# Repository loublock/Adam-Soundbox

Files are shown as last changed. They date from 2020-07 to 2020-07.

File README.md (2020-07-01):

# Soundbox

Dieses Projekt beinhaltet die Arduino Firmware, die iOS-App, die Ordnerstruktur für das Soundmodul, die CAD-Zeichnungen und die .stl-Files für die druckbaren Teile der Soundbox. 

Die Soundbox funktioniert wie folgt: Beim Einschalten wird das Soundfile 001.mp3 (variabel) aus dem Verzeichnis 01 abgespielt.
Anschließend wird ein silence-Audiofile [1] (Verzeichnis 02) in der Dauerschleife abgespielt. 
Das ist notwendig, da die Drücker mit den Audiofiles aus dem ADVERT Verzeichnis verlinkt sind und diese nur 
ausgeführt werden können, wenn bereits eine Audiodatei abgespielt wird.

Jedem Drücker kann nun Audiofile aus dem Verzeichnis ADVERT zugeordnet werden, mit der MODE (M) Taste kann
zwischen den drei Belegungslayern durchgeschaltet werden. Beim Drücken der RADIO (R) Taste werden die 
Audiofiles im MP3-Verzeichnis geshuffelt. Bei wiederholtem drücken wird ein neuer Song gestartet. 
Die Dateien im MP3-Verzeichnis müssen durchnummeriert werden (0001-9999), beachte die führenden Nullen,
es ergibt sich immer eine Zahl aus vier Ziffern. Das beigelegte rename.py file kann eure Songs automatisch umbenennen.

Die iOS-App ist eine Soundbox To-Go. Sie umfasst die selben Funktionen wie die Hardwarebox und ist in der Lage
sich mit der Soundbox via BLE zu koppeln. In diesem Modus dient die App als Remote Control für die Soundbox.

Wenn ihr eure eigene Soundbox bauen möchtet, müsst ihr folgende Schritte durchführen:

1. Klont euch das Projekt, oder downloaded es als .zip File.
2. Ladet euch die adambox.ino auf euren Arduino Nano (es müssen noch die entsprechenden Libs installiert werden).
3. Druckt euch die .stl-Files aus.
4. Verdrahtet die Hardware nach Schaltplan.
5. Baut die Box nach der CAD-Zeichnung zusammen.
6. Kopiert eure Soundfiles in die entsprechenden Verzeichnisse (siehe SD-Card). Alternativ können auch die Adamfiles genutzt werden.
7. Optional: Kopiert das Xcode Projekt, compiliert es und wählt als Target euer angeschlossenes iOS-Device aus.

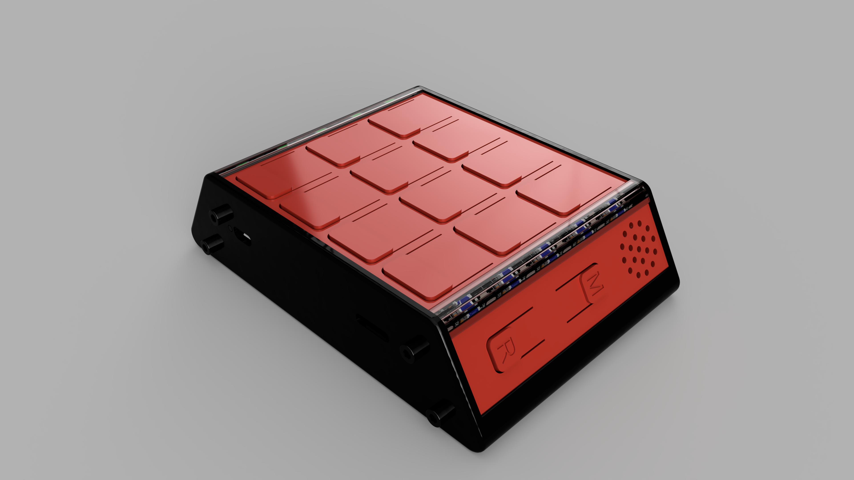
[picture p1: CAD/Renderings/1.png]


App als Soundbox           |  App als remote control
:-------------------------:|:-------------------------:
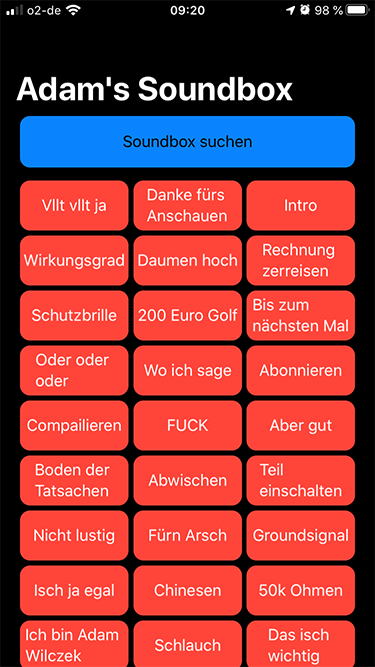
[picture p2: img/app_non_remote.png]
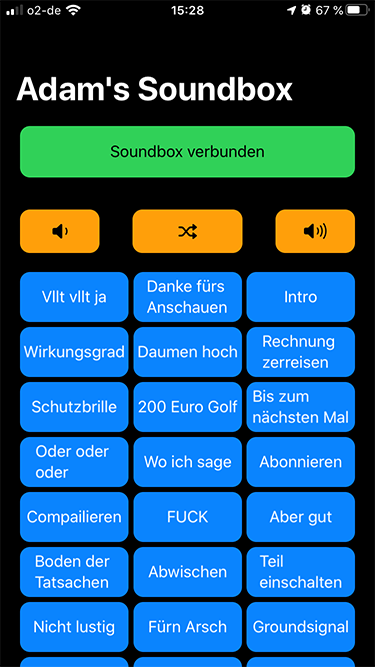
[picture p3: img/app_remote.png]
|  

1 Anar Software LLC, https://github.com/anars/blank-audio

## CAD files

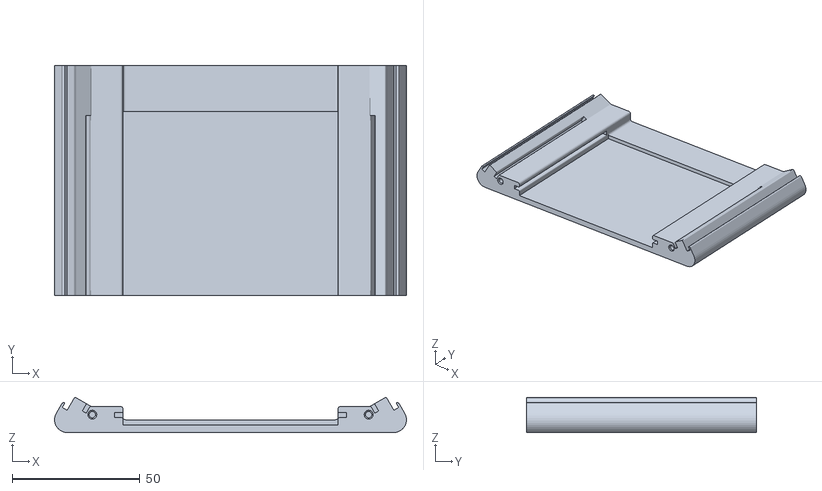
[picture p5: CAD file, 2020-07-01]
CAD/STLs/MainHousingBack.stl
137.8 x 90.0 x 13.7

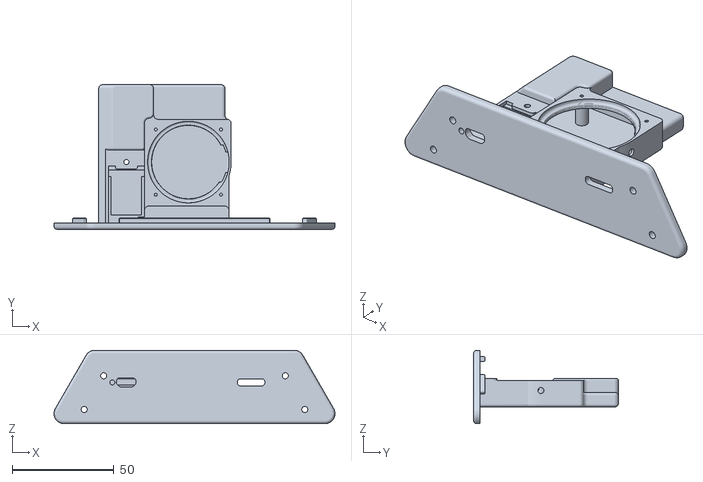
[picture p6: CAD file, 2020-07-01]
CAD/STLs/LowerSpeakerHousing.stl
137.9 x 71.0 x 36.1

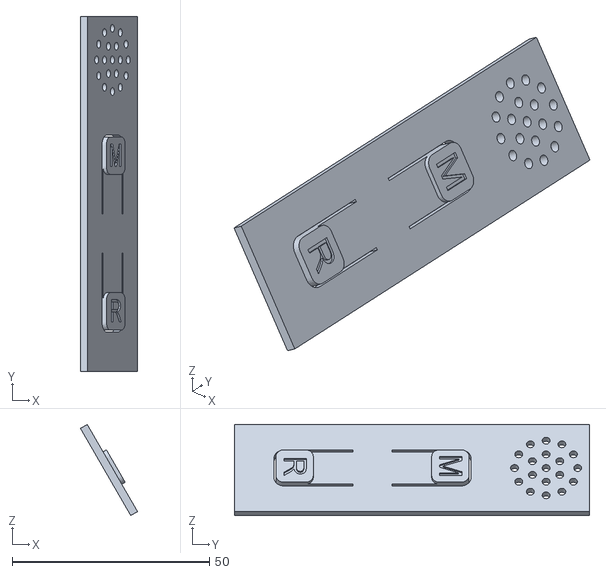
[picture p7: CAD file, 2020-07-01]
CAD/STLs/ButtonplateRight.stl
14.5 x 90.0 x 23.1

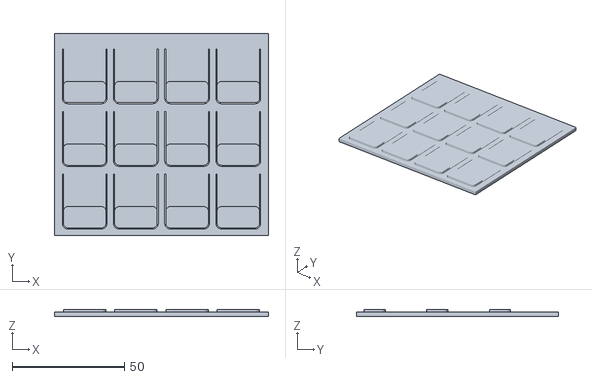
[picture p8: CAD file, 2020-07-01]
CAD/STLs/ButtonPlateTop.stl
95.5 x 90.0 x 3.00

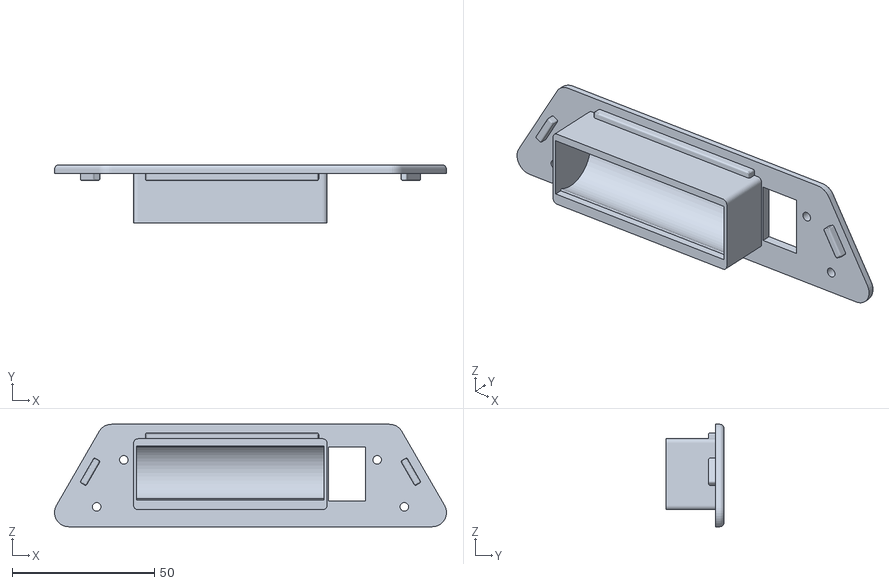
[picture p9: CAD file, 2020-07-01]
CAD/STLs/UpperBatteryHousing.stl
137.8 x 20.5 x 36.1

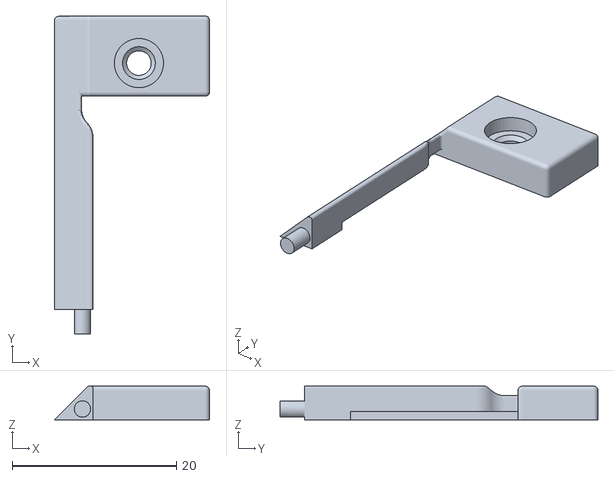
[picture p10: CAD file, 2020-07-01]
CAD/STLs/ChargingLightClamp.stl
18.9 x 38.8 x 4.10

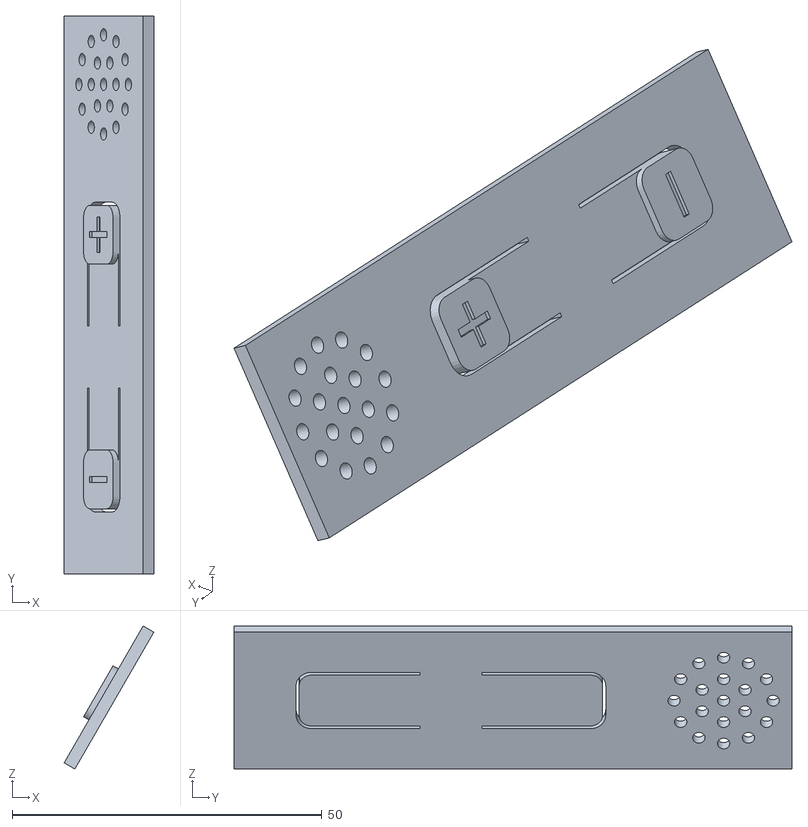
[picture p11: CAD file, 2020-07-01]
CAD/STLs/ButtonplateLeft.stl
14.5 x 90.0 x 23.1

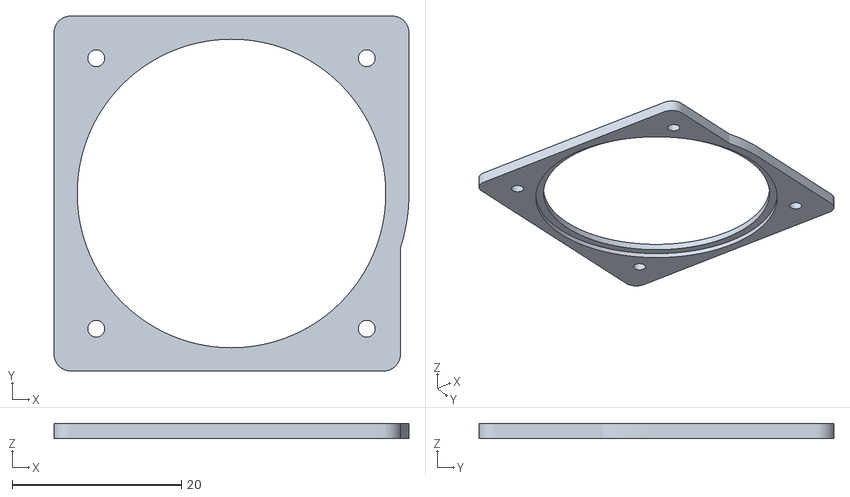
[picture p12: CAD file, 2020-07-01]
CAD/STLs/SpeakerhousingClamp.stl
42.0 x 42.0 x 1.75

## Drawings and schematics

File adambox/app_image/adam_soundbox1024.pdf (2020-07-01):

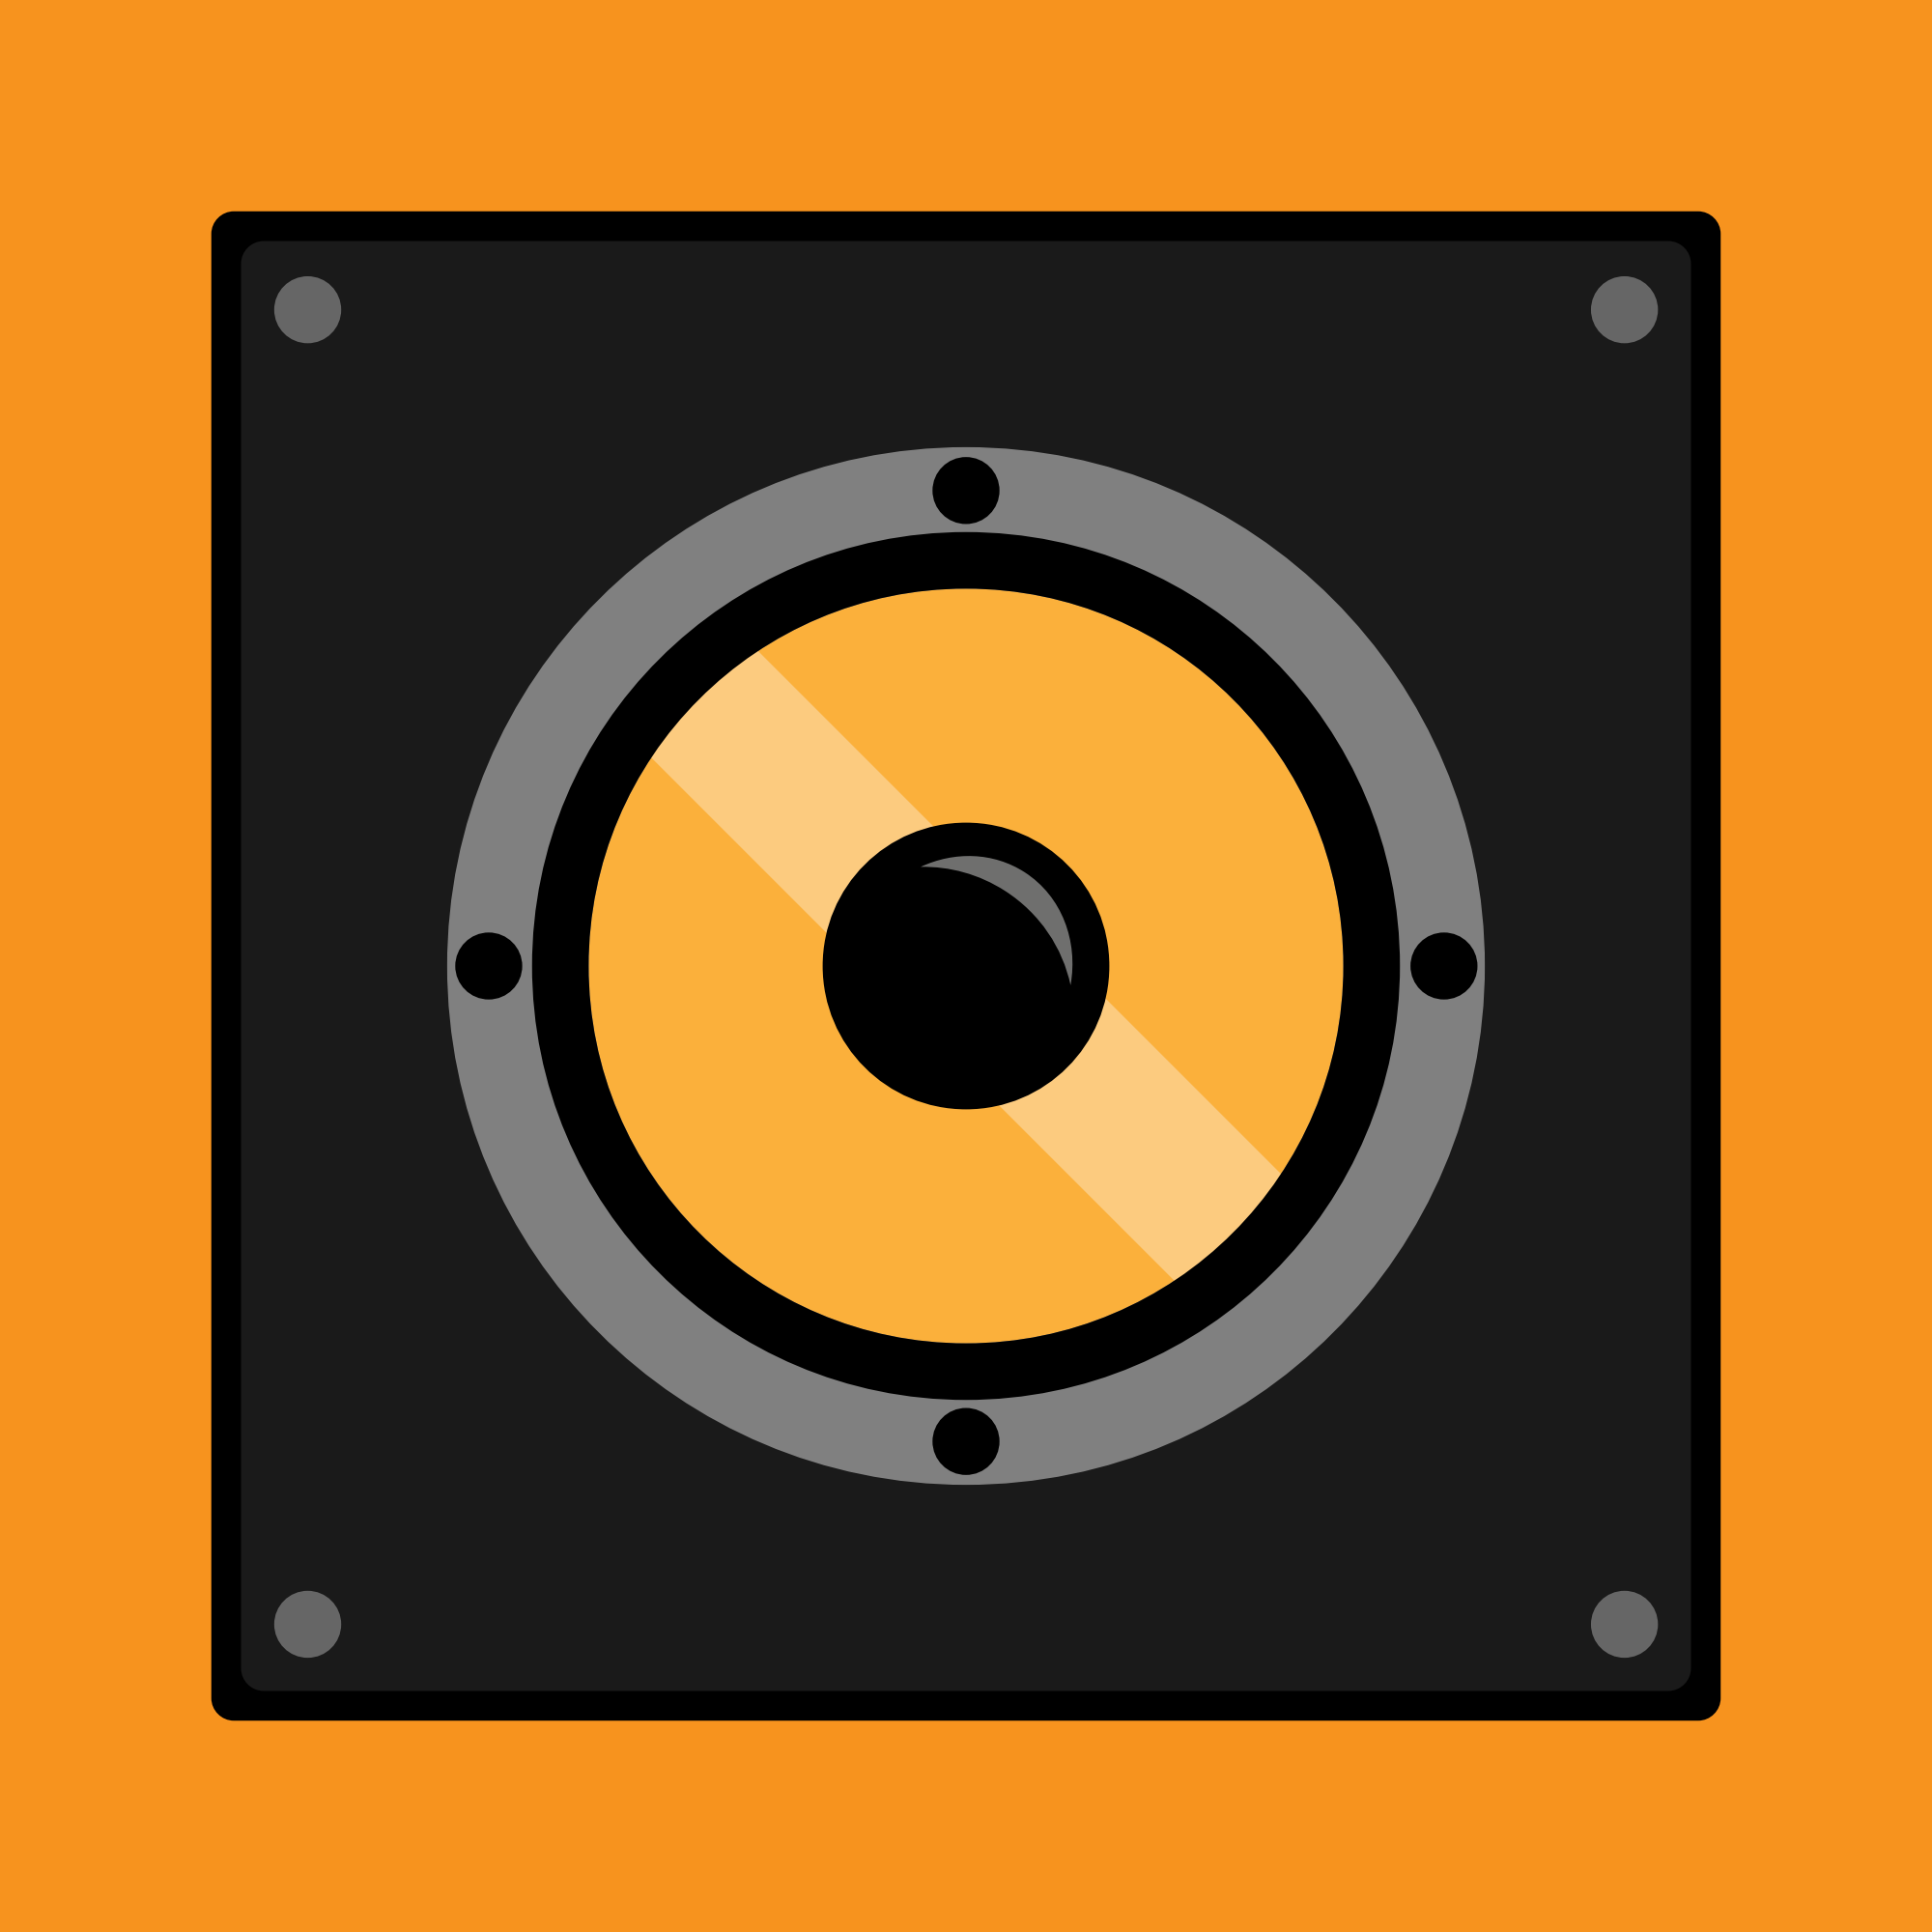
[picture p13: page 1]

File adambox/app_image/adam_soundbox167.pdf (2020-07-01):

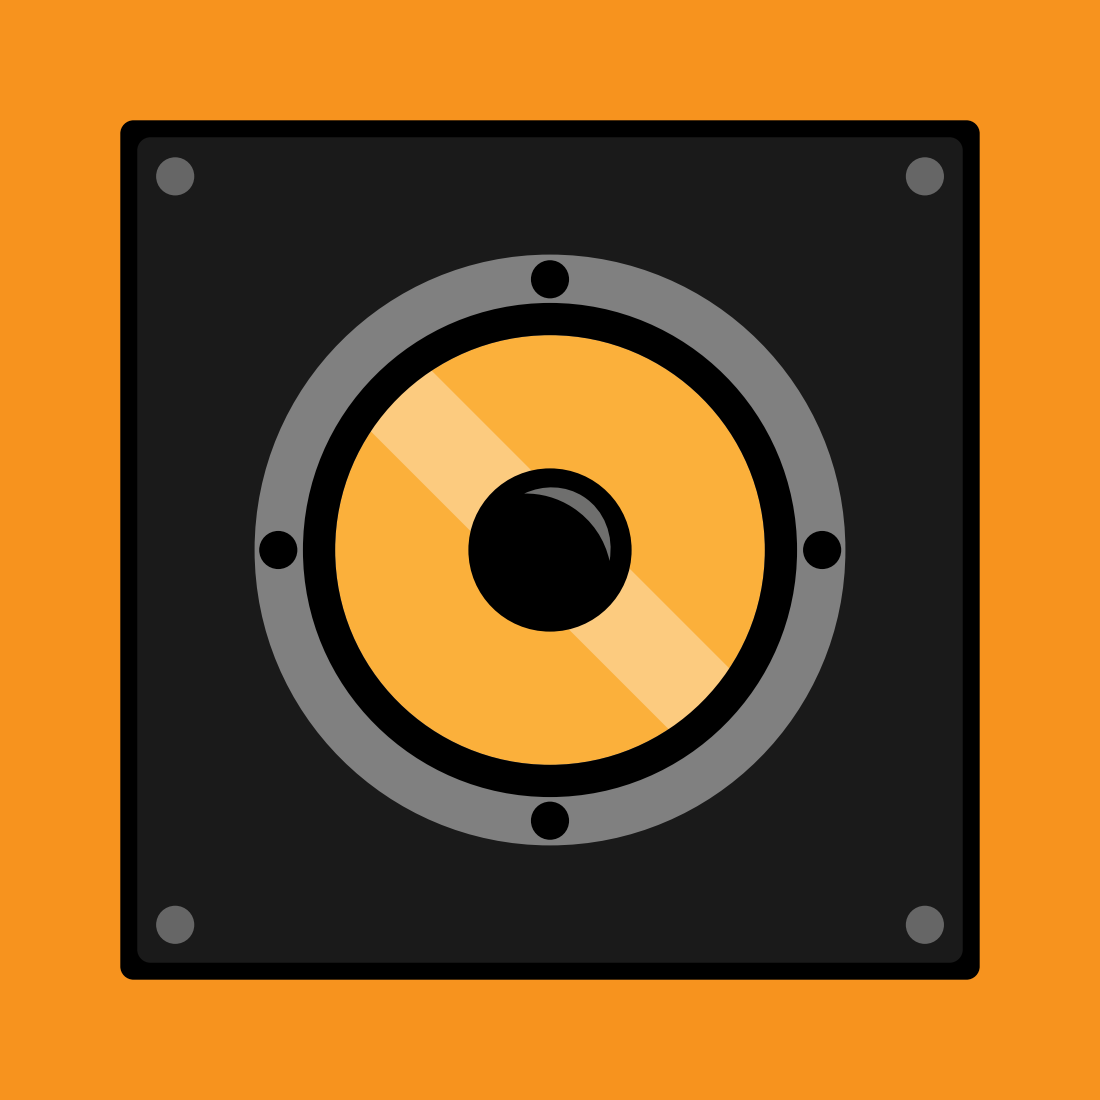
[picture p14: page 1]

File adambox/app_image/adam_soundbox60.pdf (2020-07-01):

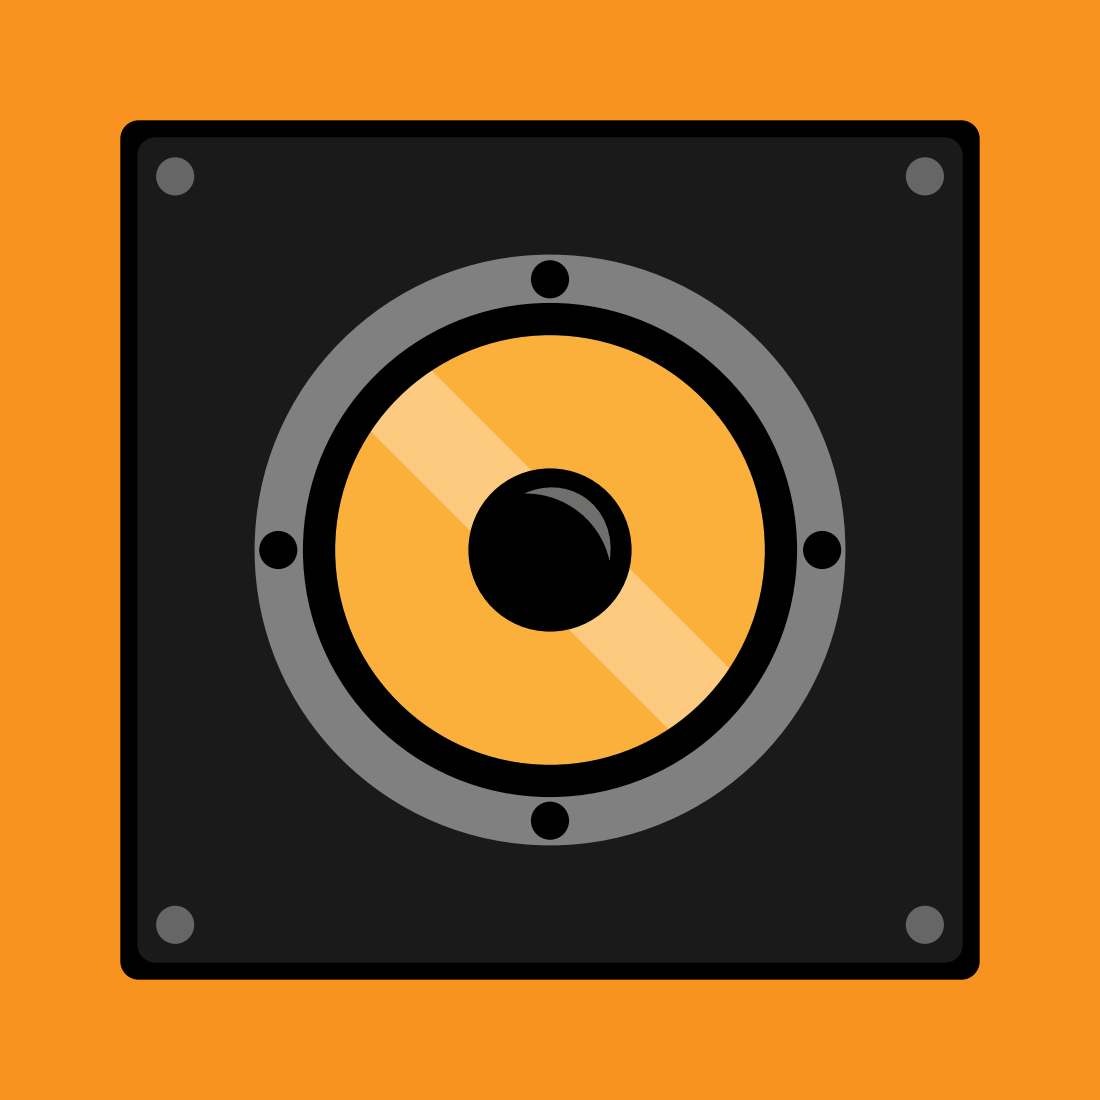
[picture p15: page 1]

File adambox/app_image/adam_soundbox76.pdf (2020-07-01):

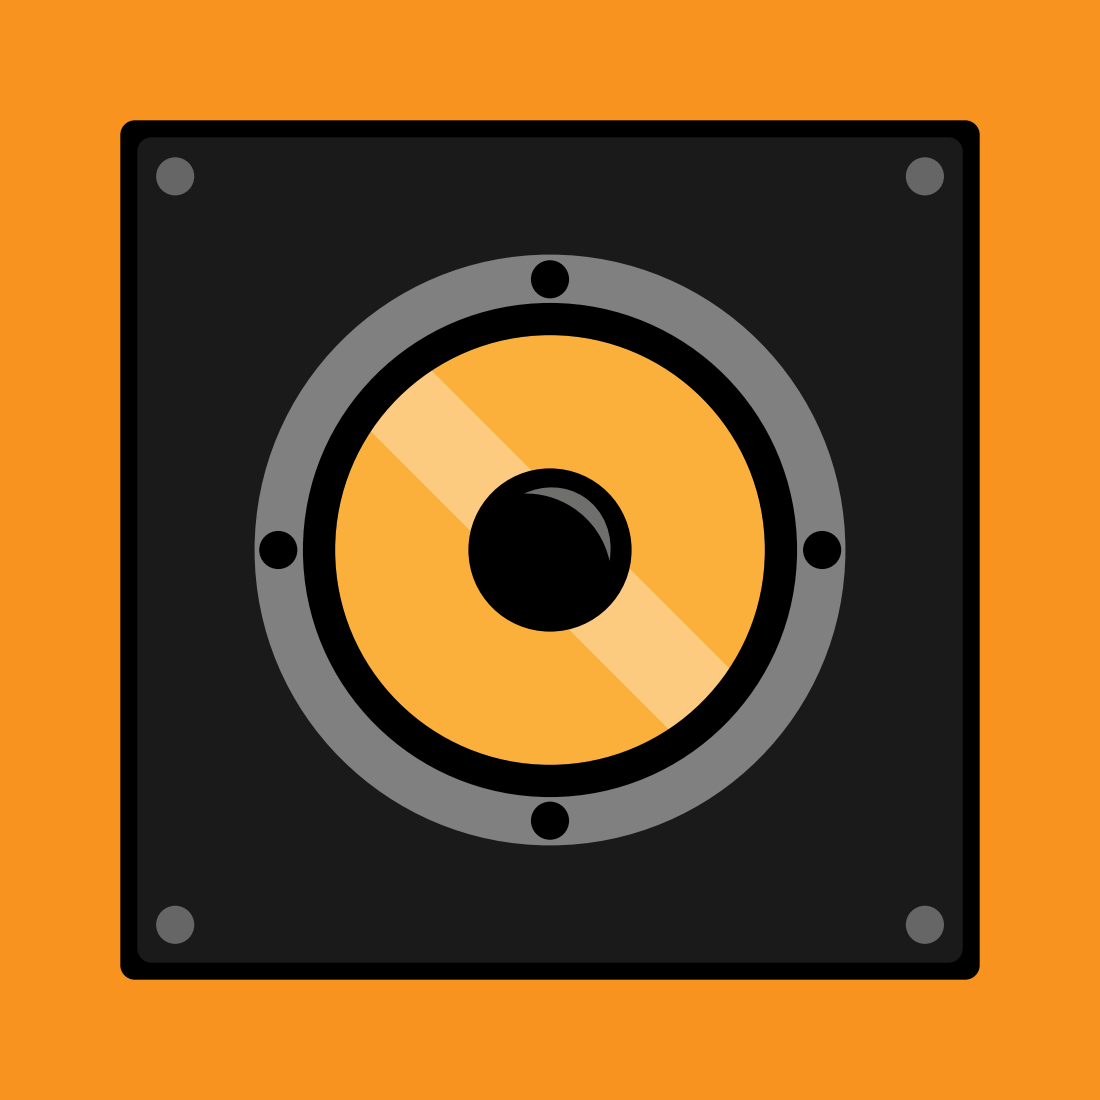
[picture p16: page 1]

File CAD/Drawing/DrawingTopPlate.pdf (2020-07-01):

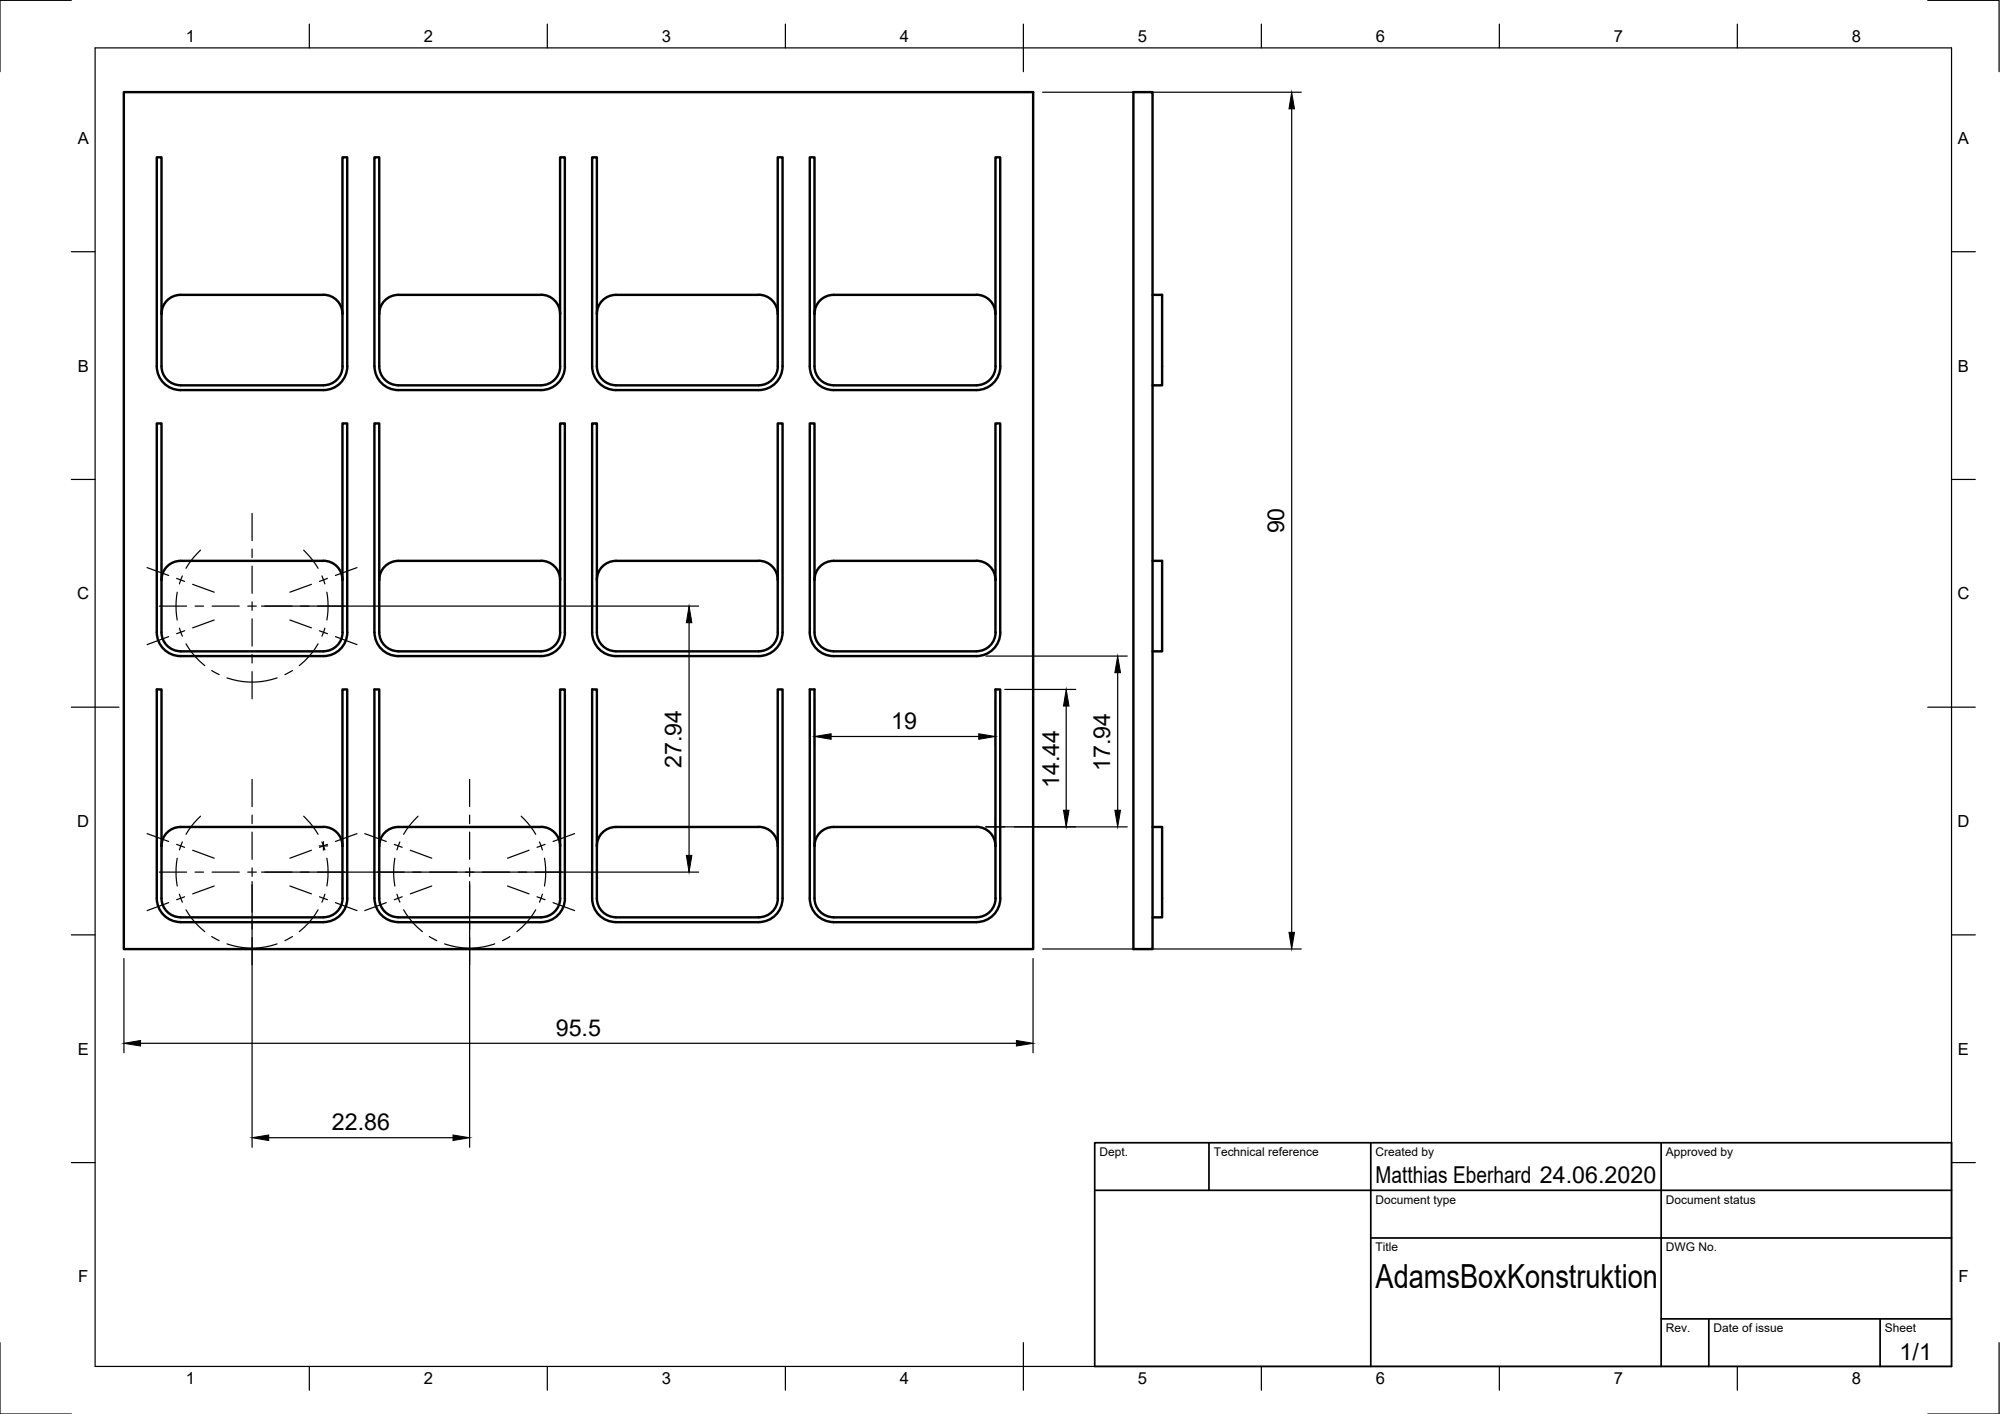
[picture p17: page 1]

Dept. | Technical reference | Created by Matthias Eberhard 24.06.2020 | Approved by

Document type | Document status

Title AdamsBoxKonstruktion | DWG No.

Rev. | Date of issue | Sheet 1/1

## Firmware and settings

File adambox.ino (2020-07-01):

#include "Arduino.h"
#include "SoftwareSerial.h"
#include "DFRobotDFPlayerMini.h"
#include <Keypad.h> //Bibliothek zum auslesen der Matrix Tasten... (4x4)
#include <Adafruit_NeoPixel.h>
#define PIXEL1_PIN    5
#define PIXEL2_PIN    6
#define PIXEL1_COUNT 5  // Number of NeoPixels
#define PIXEL2_COUNT 5  // Number of NeoPixels

Adafruit_NeoPixel strip1(PIXEL1_COUNT, PIXEL1_PIN, NEO_GRB + NEO_KHZ800);
Adafruit_NeoPixel strip2(PIXEL2_COUNT, PIXEL2_PIN, NEO_GRB + NEO_KHZ800);

SoftwareSerial mySoftwareSerial(10, 11); // RX, TX
DFRobotDFPlayerMini myDFPlayer;
void printDetail(uint8_t type, int value);
int increaseVol(int baseVol, int inc);

int a; //SerialVariable
int i = 1; //LayerMode
int rand_track = 1;
bool shuffleMP3 = false;

const byte ROWS = 4; // Reihen
const byte COLS = 4; // Spalten
char keys[ROWS][COLS] = {
  {'1','2','3','4'},
  {'5','6','7','8'},
  {'9','A','B','C'},
  {'D','E','F','G'}
};
// ReihenPins.
byte rowPins[ROWS] = { 9, 4, 3, 2 };
// SpaltenPINS.
byte colPins[COLS] = { 13, 12, 8, 7 }; 

// Create the Keypad
Keypad kpd = Keypad( makeKeymap(keys), rowPins, colPins, ROWS, COLS );


void setup()
{
  randomSeed(analogRead(0));
  mySoftwareSerial.begin(9600);
  Serial.begin(9600);
  
  Serial.println();
  Serial.println(F("Adams Magic Shoutbox"));
  Serial.println(F("Wart halt!..."));
    
  strip1.begin(); // Initialize NeoPixel strip object (REQUIRED)
  strip1.show();  // Initialize all pixels to 'off'
  strip2.begin(); // Initialize NeoPixel strip object (REQUIRED)
  strip2.show();  // Initialize all pixels to 'off'
  

  if (!myDFPlayer.begin(mySoftwareSerial)) {  //Use softwareSerial to communicate with mp3.
    Serial.println(F("Unable to begin:"));
    Serial.println(F("1.Please recheck the connection!"));
    Serial.println(F("2.Please insert the SD card!"));
    while(true);
  }
  Serial.println(F("DFPlayer Mini online."));
  
  myDFPlayer.setTimeOut(500); //Set serial communictaion time out 500ms
  
  //----Set volume----
  myDFPlayer.volume(20);  //Set volume value (0~30).
  //myDFPlayer.volumeUp(); //Volume Up
  //myDFPlayer.volumeDown(); //Volume Down
  
  //----Set different EQ----
  myDFPlayer.EQ(DFPLAYER_EQ_NORMAL);
  myDFPlayer.outputDevice(DFPLAYER_DEVICE_SD);

  
  Serial.print("Aktuelle Lautstärke: ");
  Serial.println(myDFPlayer.readVolume()); //read current volume
  Serial.print("Anzahl an Titel auf SD-Karte: ");
  Serial.println(myDFPlayer.readFileCounts()); //read all file counts in SD card
  
  colorWipe(strip1.Color(0,   50,   0), 120);    // green
  colorWipe(strip2.Color(0,   50,   0), 120);    // green

  myDFPlayer.playFolder(1, 1);  //danke fürs einschaltenm
  delay(1500);
  myDFPlayer.loopFolder(2); //loop 5s silence
}

void loop()
{
    char key = kpd.getKey();
    if(key)  // Check for a valid key.
    {
      switch (key)
      {
        case '1':
          Serial.println("1: LayerMode");
          if(i<3){
            i++;
          }
          else{
            i=1;
          }
          Serial.println(i);
          if(i==1){
          LightMode0();
          }
          if(i==2){
          LightMode1();        
          }
          if(i==3){
          LightMode2();        
          }
          break;
        case '2':
          Serial.println("2: Shuffle");
          //myDFPlayer.randomAll(); //Random play all the mp3.
          randomMP3();
          break;
        case '3':
          Serial.println("3: Lauter");
          myDFPlayer.volumeDown(); //Volume Up
          break;  
        case '4':
          Serial.println("4: Leiser");
          myDFPlayer.volumeUp(); //Volume Down
          break;   
        case '5':
          Serial.println("5");
          myDFPlayer.advertise(1+(i-1)*12);  //play specific mp3 in SD:/1/001.mp3; Folder Name(1~99); File Name(1~255)
          break;
        case '6':
          Serial.println("6");
          myDFPlayer.advertise(2+(i-1)*12);  //play specific mp3 in SD:/1/001.mp3; Folder Name(1~99); File Name(1~255)
          break;
        case '7':
          Serial.println("7");
          myDFPlayer.advertise(3+(i-1)*12);  //play specific mp3 in SD:/1/001.mp3; Folder Name(1~99); File Name(1~255)
          break;  
        case '8':
          Serial.println("8");
          myDFPlayer.advertise(4+(i-1)*12);  //play specific mp3 in SD:/1/001.mp3; Folder Name(1~99); File Name(1~255)
          break;   
        case '9':
          Serial.println("9");
          myDFPlayer.advertise(5+(i-1)*12);  //play specific mp3 in SD:/1/001.mp3; Folder Name(1~99); File Name(1~255)
          break;
        case 'A':
          Serial.println("A");
          myDFPlayer.advertise(6+(i-1)*12);  //play specific mp3 in SD:/1/001.mp3; Folder Name(1~99); File Name(1~255)
          break;
        case 'B':
          Serial.println("B");
          myDFPlayer.advertise(7+(i-1)*12);  //play specific mp3 in SD:/1/001.mp3; Folder Name(1~99); File Name(1~255)
          break;  
        case 'C':
          Serial.println("C");
          myDFPlayer.advertise(8+(i-1)*12);  //play specific mp3 in SD:/1/001.mp3; Folder Name(1~99); File Name(1~255)
          break;  
        case 'D':
          Serial.println("D");
          myDFPlayer.advertise(9+(i-1)*12);  //play specific mp3 in SD:/1/001.mp3; Folder Name(1~99); File Name(1~255)
          break;
        case 'E':
          Serial.println("E");
          myDFPlayer.advertise(10+(i-1)*12);  //play specific mp3 in SD:/1/001.mp3; Folder Name(1~99); File Name(1~255)
          break;
        case 'F':
          Serial.println("F");
          myDFPlayer.advertise(11+(i-1)*12);  //play specific mp3 in SD:/1/001.mp3; Folder Name(1~99); File Name(1~255)
          break;  
        case 'G':
          Serial.println("G");
          myDFPlayer.advertise(12+(i-1)*12);  //play specific mp3 in SD:/1/001.mp3; Folder Name(1~99); File Name(1~255)
          break;                                
        default:
          Serial.println("ERROR");
      }
    }
  
  //Serielle Kommunikation mit BLE modul:
  if (Serial.available())
  {
    a = Serial.parseInt();
    int track_count = 36;
      
    if (a == 99)
    {
      //myDFPlayer.randomAll(); //Random play all the mp3.
      randomMP3();
    }
    else if (a == 98) 
    {
      myDFPlayer.volume(adjustVolume(myDFPlayer.readVolume(), 5));
    }
    else if (a == 97) 
    {
      myDFPlayer.volume(adjustVolume(myDFPlayer.readVolume(), -5));
    }
    else if ((a >= 0) && (a < track_count))
    {
      //iphone plist starts at 0
      myDFPlayer.advertise(a+1); 
    }
    else
    {
      return;
    }
  }
  
  //Informationen Seriell ausgeben:
  if (myDFPlayer.available())
  {
    printDetail(myDFPlayer.readType(), myDFPlayer.read()); //Print the detail message from DFPlayer to handle different errors and states.
  }
}

int adjustVolume(int baseVol, int inc)
{
  int vol = 20;
  vol = baseVol;
  vol = baseVol + inc;
  if (vol > 30)
  {
    vol = 30;
  }
  else if (vol < 0)
  {
    vol = 0;
  }
  return vol;
}

void randomMP3()
{
    //only working when hit the random generator twice
    //otherwise track 1 is always played
    rand_track = random(1,myDFPlayer.readFileCounts()+1-38);
    rand_track = random(1,myDFPlayer.readFileCounts()+1-38);
    Serial.println(rand_track);
    char buffer[30];
    sprintf(buffer, "Number %d", rand_track);
    myDFPlayer.playMp3Folder(rand_track);
    shuffleMP3 = true;
}

void rainbow(int wait) {
  for(long firstPixelHue = 0; firstPixelHue < 3*65536; firstPixelHue += 256) {
    for(int i=0; i<strip1.numPixels(); i++) { // For each pixel in strip...
      int pixelHue1 = firstPixelHue + (i * 65536L / strip1.numPixels());
      int pixelHue2 = firstPixelHue + (i * 65536L / strip2.numPixels());
      strip1.setPixelColor(i, strip1.gamma32(strip1.ColorHSV(pixelHue1)));
      strip2.setPixelColor(i, strip2.gamma32(strip2.ColorHSV(pixelHue2)));
    }
    strip1.show(); // Update strip with new contents
    strip2.show(); // Update strip with new contents
    delay(wait);  // Pause for a moment
  }
}
void LightModeWelcome(){
  strip1.setPixelColor(0, strip1.Color(50, 50, 50));
  strip1.setPixelColor(1, strip1.Color(50, 50, 50));
  strip1.setPixelColor(2, strip1.Color(50, 50, 50));
  strip1.setPixelColor(3, strip1.Color(50, 50, 50));
  strip1.setPixelColor(4, strip1.Color(50, 50, 50));
  strip1.setPixelColor(5, strip1.Color(50, 50, 50));

  strip2.setPixelColor(0, strip2.Color(50, 50, 50));
  strip2.setPixelColor(1, strip2.Color(50, 50, 50));
  strip2.setPixelColor(2, strip2.Color(50, 50, 50));
  strip2.setPixelColor(3, strip2.Color(50, 50, 50));
  strip2.setPixelColor(4, strip2.Color(50, 50, 50));
  strip2.setPixelColor(5, strip2.Color(50, 50, 50));

  strip1.show();
  strip2.show();
}

void LightMode0(){
  strip1.setPixelColor(0, strip1.Color(0, 50, 0));
  strip1.setPixelColor(1, strip1.Color(0, 50, 0));
  strip1.setPixelColor(2, strip1.Color(0, 50, 0));
  strip1.setPixelColor(3, strip1.Color(0, 50, 0));
  strip1.setPixelColor(4, strip1.Color(0, 50, 0));
  strip1.setPixelColor(5, strip1.Color(0, 50, 0));

  strip2.setPixelColor(0, strip2.Color(0, 50, 0));
  strip2.setPixelColor(1, strip2.Color(0, 50, 0));
  strip2.setPixelColor(2, strip2.Color(0, 50, 0));
  strip2.setPixelColor(3, strip2.Color(0, 50, 0));
  strip2.setPixelColor(4, strip2.Color(0, 50, 0));
  strip2.setPixelColor(5, strip2.Color(0, 50, 0));

  strip1.show();
  strip2.show();
}
void LightMode1(){
  strip1.setPixelColor(0, strip1.Color(50, 0, 0));
  strip1.setPixelColor(1, strip1.Color(50, 0, 0));
  strip1.setPixelColor(2, strip1.Color(50, 0, 0));
  strip1.setPixelColor(3, strip1.Color(50, 0, 0));
  strip1.setPixelColor(4, strip1.Color(50, 0, 0));
  strip1.setPixelColor(5, strip1.Color(50, 0, 0));

  strip2.setPixelColor(0, strip2.Color(50, 0, 0));
  strip2.setPixelColor(1, strip2.Color(50, 0, 0));
  strip2.setPixelColor(2, strip2.Color(50, 0, 0));
  strip2.setPixelColor(3, strip2.Color(50, 0, 0));
  strip2.setPixelColor(4, strip2.Color(50, 0, 0));
  strip2.setPixelColor(5, strip2.Color(50, 0, 0));

  strip1.show();
  strip2.show();
}
void LightMode2(){
  strip1.setPixelColor(0, strip1.Color(0, 0, 50));
  strip1.setPixelColor(1, strip1.Color(0, 0, 50));
  strip1.setPixelColor(2, strip1.Color(0, 0, 50));
  strip1.setPixelColor(3, strip1.Color(0, 0, 50));
  strip1.setPixelColor(4, strip1.Color(0, 0, 50));
  strip1.setPixelColor(5, strip1.Color(0, 0, 50));

  strip2.setPixelColor(0, strip2.Color(0, 0, 50));
  strip2.setPixelColor(1, strip2.Color(0, 0, 50));
  strip2.setPixelColor(2, strip2.Color(0, 0, 50));
  strip2.setPixelColor(3, strip2.Color(0, 0, 50));
  strip2.setPixelColor(4, strip2.Color(0, 0, 50));
  strip2.setPixelColor(5, strip2.Color(0, 0, 50));

  strip1.show();
  strip2.show();
}

void colorWipe(uint32_t color, int wait) {
  for(int i=0; i<strip1.numPixels(); i++) { // For each pixel in strip...
    strip1.setPixelColor(i, color);         //  Set pixel's color (in RAM)
    strip2.setPixelColor(i, color);         //  Set pixel's color (in RAM)
    strip1.show();                          //  Update strip to match
    strip2.show();                          //  Update strip to match
    delay(wait);                           //  Pause for a moment
  }
}

void theaterChase(uint32_t color, int wait) {
  for(int a=0; a<10; a++) {  // Repeat 10 times...
    for(int b=0; b<3; b++) { //  'b' counts from 0 to 2...
      strip1.clear();         //   Set all pixels in RAM to 0 (off)
      // 'c' counts up from 'b' to end of strip in steps of 3...
      for(int c=b; c<strip1.numPixels(); c += 3) {
        strip1.setPixelColor(c, color); // Set pixel 'c' to value 'color'
      }
      strip1.show(); // Update strip with new contents
      delay(wait);  // Pause for a moment
    }
  }
}

void printDetail(uint8_t type, int value){
  switch (type) {
    case TimeOut:
      Serial.println(F("Time Out!"));
      if (shuffleMP3)
      {
        randomMP3();
      }
      break;
    case WrongStack:
      Serial.println(F("Stack Wrong!"));
      break;
    case DFPlayerCardInserted:
      Serial.println(F("Card Inserted!"));
      break;
    case DFPlayerCardRemoved:
      Serial.println(F("Card Removed!"));
      break;
    case DFPlayerCardOnline:
      Serial.println(F("Card Online!"));
      break;
    case DFPlayerUSBInserted:
      Serial.println("USB Inserted!");
      break;
    case DFPlayerUSBRemoved:
      Serial.println("USB Removed!");
      break;
    case DFPlayerPlayFinished:
      Serial.print(F("Number:"));
      Serial.print(value);
      Serial.println(F(" Play Finished!"));
      if (shuffleMP3)
      {
        randomMP3();
      }
      break;
    case DFPlayerError:
      Serial.print(F("DFPlayerError:"));
      switch (value) {
        case Busy:
          Serial.println(F("Card not found"));
          break;
        case Sleeping:
          Serial.println(F("Sleeping"));
          break;
        case SerialWrongStack:
          Serial.println(F("Get Wrong Stack"));
          break;
        case CheckSumNotMatch:
          Serial.println(F("Check Sum Not Match"));
          if (shuffleMP3)
          {
            randomMP3();
          }
          break;
        case FileIndexOut:
          Serial.println(F("File Index Out of Bound"));
          break;
        case FileMismatch:
          Serial.println(F("Cannot Find File"));
          break;
        case Advertise:
          Serial.println(F("In Advertise"));
          break;
        default:
          break;
      }
      break;
    default:
      break;
  }
  
}
